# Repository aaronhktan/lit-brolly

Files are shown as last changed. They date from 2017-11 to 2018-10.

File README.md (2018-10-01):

# Lit Brolly

*Nōn omne quod nitet aurum est.*

A project by Aaron Tan, Lily Yang, and [Hengcheng Yu](https://github.com/handchan) to make your brollies lit. The LEDs change colour based on the movement detected by the accelerometer!



---

### Contents
1. [Setup](#setup)
	- [Requirements](#requirements)
	- [Compilation](#compilation)
	- [Hardware](#hardware)
	- [Execution](#execution)
2. [Usage](#usage)
	- [Synergy](#synergy)
	- [Arduino](#arduino)
	- [ADXL345](#adxl345)
3. [Miscellaneous](#miscellaneous)
	- [Acknowledgements](#acknowledgements)
	- [License](#license)

---

## Setup
### Requirements
- Onion Omega2 (should work with the 2+ but this has not been tested)
- Arduino Dock R2
- Neopixels
- ADXL345 accelerometer
- Time. Lots of it.

### Compilation

**Note: Pre-compiled executables are available in the folder ```Code/executable```. Only follow the instructions under the Compilation heading if you really want to compile from source.**

- Set up the virtual machine as described in the PDF labelled "SetupCrossCompilingEnvironmentV1.pdf" in ```Docs/Compile```. In the ```make menuconfig``` step, include the onioni2c library. This will take upwards of an hour of your time.
- Modify the target of the makefile under the compile folder to the name of the file that you wish to compile. By default, it will try to compile ```Synergy.cpp```.
- Move the file you want to compile into the same folder as your ```makefile``` and ```xCompile.sh```.
- Once the makefile, the target, and xCompile.sh are in the same folder, run xCompile.sh as described in the PDF labelled "CompilingCppCodeOmega.pdf" in ```Docs/Compile```. An executable file will be generated in the same folder.

### Hardware
- Solder the Neopixels and hook them up to the Arduino Dock R2 headers as described in the schematic under ```Docs/Schematics```. This project supports hooking up to five strands of Neopixels; connect the power wires in series and data pins to 6, 7, 8, 9, and 10 on the Arduino Dock R2 headers.
- Solder header pins on the ADXL345 as necessary and hook them up to the Onion Expansion headers as described in the schematic under ```Docs/Schematics```.
- A breadboard may prove handy for cable management and organization. See ```Example.png``` under ```Docs/Schematics``` for an real-life example of this schematic put together.

### Execution
- Move your executable to a USB stick, then mount it on your Omega:
	- Connect to your Omega's Wi-Fi network, then using PuTTY on Windows or your terminal on Mac/Linux: ```ssh root@192.168.3.1```. You will need to type in the password for the Omega2: default is onioneer.
	- In the terminal: ```mkdir /mnt/usb``` (first time only, making a directory to be the mount point for your USB stick) then ```mount /dev/sda1 /mnt/usb``` (actually mounting the USB)
- Connect to the Arduino Dock (I prefer wirelessly, but it shouldn't matter), and upload the ```ardu.ino``` sketch under ```Code/src```.
- Run Synergy from the command line: ```/mnt/usb/Synergy``` (assuming you followed the previous directions)
- If you wire up the Neopixels correctly (i.e. the way it's described under the "Final Project Report" appendix), then you should see your Neopixels light up when you move around the accelerometer!

## Usage
### Synergy
Main program; puts everything together (synergy... hahaha get it?). Running the file requires no command line arguments.

- Program will continually pull accelerometer readings every second and output to terminal.
- Lights will change colour every second.
- Generates two log files directly on the Omega2; can be accessed by ```cat```:
	- ```log.txt``` logs, with timestamp, the last readings of the accelerometer and the status of the I2C write command to the Neopixels.
	- ```histogram.txt``` logs, with timestamp of generation time, a histogram of the x, y, and z accelerations as well as total acceleration over the period that the program runs. It is updated every ten seconds with new accelerometer values.
- **Must have ardu.ino sketch running on the Arduino dock for this to work.**

### Arduino
Program to test Neopixels. Starting program requires four integer command line arguments: ```[brightness] [red value] [green value] [blue value]```

- Program sets all Neopixels to the RGB values specified by arguments. Brightness value is vestigial and doesn't actually do anything.
- **Must have ardu.ino running on the Arduino dock for this to work.**

### ADXL345
Program to test the accelerometer. No command line arguments required.

- Pulls accelerometer values every second and outputs to command line.

## Miscellaneous
### Acknowledgements
Big thanks to Austin Jiang for his vehicle.

Big thanks to (Aaaaaaaaaaaaaaaaaaaaaaaa)Kash Pirani for his soldering and head patting skills.

Big thanks to Edward Yang and Shun Yu Rao for moral support and their USB sticks.

Big thanks to Google Assistant, Cortana, and Siri for turning on and off the lights.

Big thanks to Ferrero Rocher for being the Official Snack Food™ of this project.

### License
See LICENSE.md for more details.

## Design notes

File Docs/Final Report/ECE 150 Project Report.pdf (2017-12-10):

# Lit Brolly

Nōn omne quod nitet aurum est.

Aaron Tan
Lily Yang
Hengcheng Yu

Group #25

Project Overview
The idea behind the project was to make a LED Blade Runner inspired umbrella—lining the spokes of a clear umbrella with LEDs and changing their colour and intensity based on the orientation and speed of the umbrella.

To implement this idea, we used the Omega2 to take an input from the accelerometer (through the SDA/SCL pins), mapping these to R, G, and B values from 0-255. We then sent them over to the Arduino over I2C, where the microcontroller sets colour and the intensity and colour of the Neopixel strips through its digital pinouts (6-10).

Originally we intended to communicate with the Neopixel LEDs through SPI; however, the very specific timings required by the Neopixels could not be controlled precisely enough by the Omega2. Instead, we used the I2C and the Arduino Adafruit Neopixel library, which were both better documented, to communicate with the LEDs. We also had stretch goals of allowing users to be able to switch between lighting profiles through a phone or web interface, but this was deemed unfeasible during the timeframe allotted.

Original Features | Final Features
Take input from the accelerometer (through either SPI or I2C) | Take input from the accelerometer through I2C
Take input from a gyroscope (through either SPI or I2C) (not included in our original project proposal but added shortly after submission) | Gyroscope was not used
Change intensity of LEDs (through SPI, backup plan: use Arduino Adafruit Neopixel library) | Control the brightness of the LEDs through the Arduino Adafruit Neopixel library
Change colour of LEDs (through SPI, backup plan: use Arduino Adafruit Neopixel library) | Control the colour of the LEDs through the Arduino Adafruit Neopixel library
Log accelerometer readings | Log accelerometer readings with timestamp, status upon writing I2C values to different registers, and histogram of past accelerometer readings to text files on the Omega
A strand of LEDs along each of the 8 spokes | A strand of LEDs along each of 4 spokes, plus a bonus circular pattern
Allow user to be able to switch lighting profiles through a phone or web interface | Was not implemented, but program can be controlled via SSH to test different colours

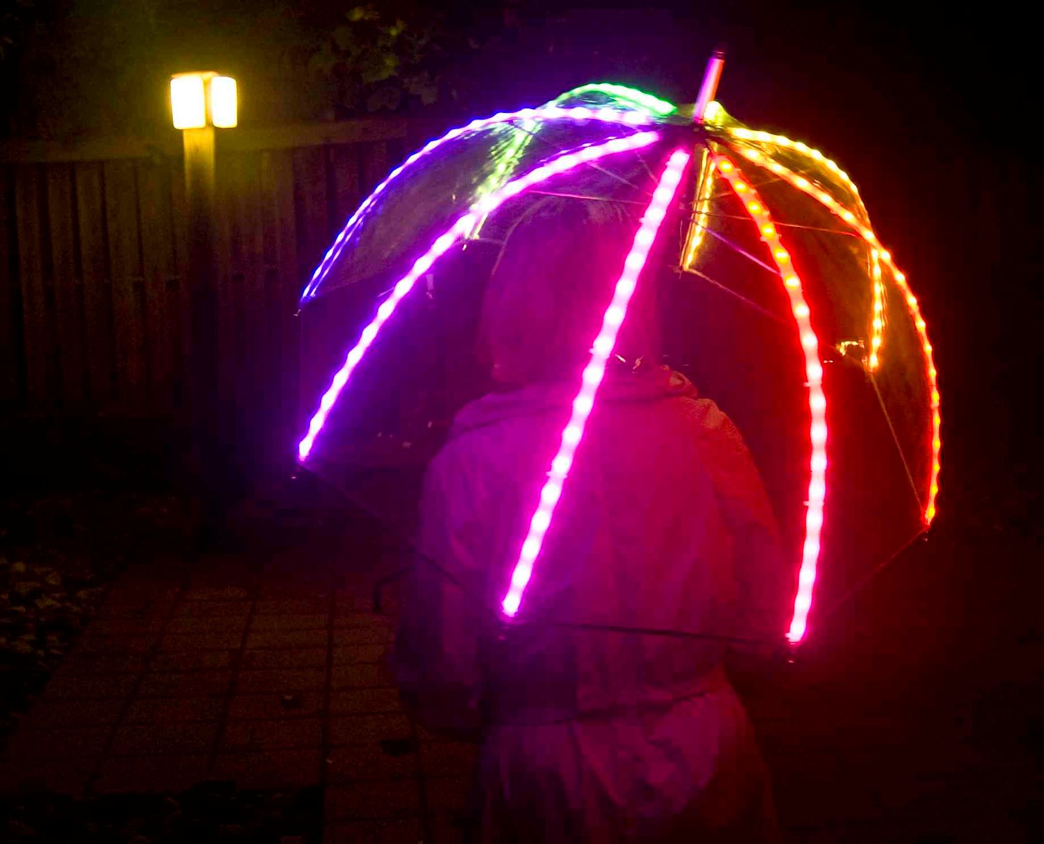
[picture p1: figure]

System Design
Hardware Components:
- Omega2

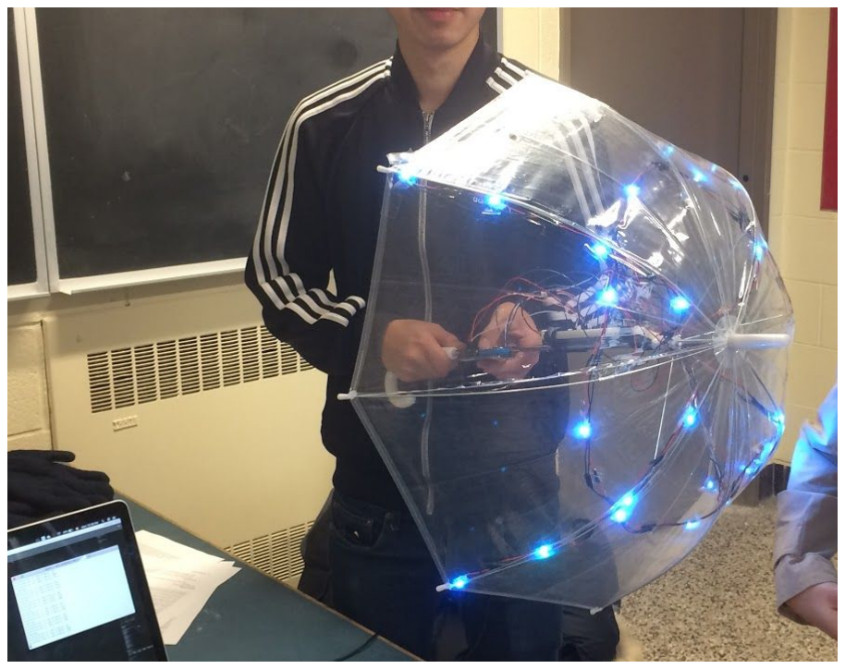
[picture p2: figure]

| ○ We used the Onion Omega2 that was provided for us.
- Arduino Dock R2
| ○ We used the Onion Arduino Dock for the Omega2. The dock has identical pin
layouts to the Arduino and since they share the same microcontroller (the ATMega328P), using the dock with the Onion gives us access to Arduino hardware as a slave device to the Omega2.
- Neopixel LEDs
| ○ We used WS2812B APA102 individually addressable smart full-color LED pixel
made by Kuman.
| ○ We soldered wires to connect them together into a daisy chain. One strip of LEDs
contains 4 individual LEDs and are intended to line one spoke. We hot glued the back of each of the LEDs soldering pads to ensure that the wires would stay in place, then taped the strips to the spokes of the umbrella.
- Accelerometer
| ○ We used a ADXL345 accelerometer module made by OSEPP. It is a 3-axis MEMS
accelerometer with 13-bit resolution measurement at up to +-16 g that can use both SPI and I2C.
| ○ We used I2C to interface with the accelerometer.

- 3.7V 2Ah Lithium-ion Battery and Xiaomi 20Ah Power Bank
- We used a 2Ah battery to power the LEDs through a JST-PH connector connected to the breadboard.
- We used a 20Ah portable power bank to provide power to the Omega through a Micro-USB B connector.
- Wires
- Wires were used to make all the connections.
- Breadboard
- A breadboard was used to house the accelerometer and connect the neopixels and accelerometer to the Arduino Dock.
- The breadboard was strapped onto the handle of the umbrella using tape.
- Resistors
- 5 1k ohm resistors were used for the neopixels (to protect the LEDs).
- 1 10k ohm resistor was used as the pull up resistor to connect the accelerometer to the Arduino Dock (for I2C).
- These resistors were placed on the breadboard.
- Umbrella
- 34 inch child sized clear umbrella.

Software Design
Flowchart for the main program

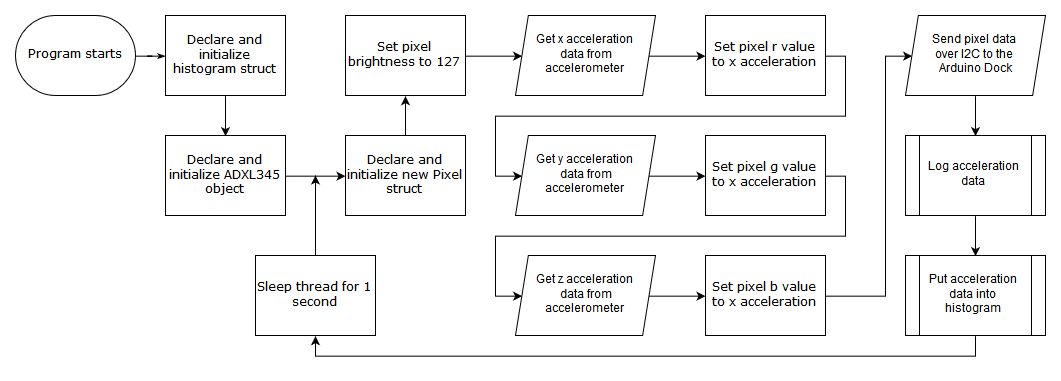
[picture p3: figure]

UML class diagrams for Sensor abstract class and subclasses

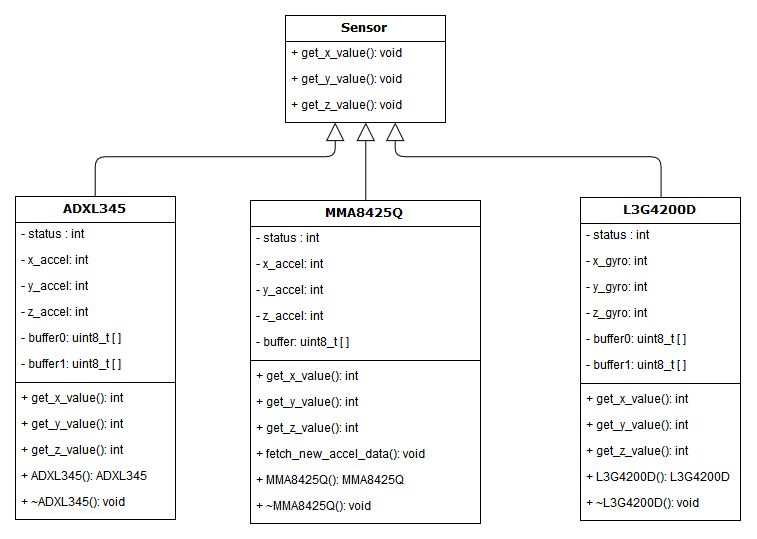
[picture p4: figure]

Class explanations:
- Sensor is an abstract class that has only virtual member functions: get_x_value(), get_y_value(), and get_z_value(). These are meant to be overridden in any child classes, and generically serve to get the x, y, and z, values from any particular sensor.
- ADXL345 is a derived class from base class Sensor. Here, public member functions
get_x_value(), get_y_value(), and get_z_value() have been overridden and
return the x, y, and z accelerations respectively in the form of an int ranging from 0 to 255. We also define a constructor ADXL345() and destructor ~ADXL345() in order to set up the accelerometer correctly (by writing to data registers to tell it to turn on, set sensitivity, and others). In terms of member variables, we have a private status, that changes depending on the success or failure of writing to I2C addresses, x_accel, y_accel, and z_accel, that contain the values of acceleration, and buffer0 and buffer1, which contain the direct readings from the accelerometer (least significant bit and most significant bit respectively).

- MMA8425Q is another derived class from base class Sensor. Here, public member
functions get_x_value(), get_y_value(), and get_z_value() have also been
overridden and return the x, y, and z accelerations respectively in the form of an int ranging from 0 to 255. We define get_new_accel_data() to update the buffer in which acceleration data occurs; here, all the data is contained in one register as opposed to the many in ADXL345 and L3G4200D. We also define a constructor MMA8425Q() and destructor ~MMA8425Q() in order to set up the accelerometer correctly (by writing to data registers to tell it to turn on, set sensitivity, and others). In terms of member variables, we have a private status, that changes depending on the success or failure of writing to I2C addresses, x_accel, y_accel, and z_accel, that contain the values of acceleration, and buffer, which contains 7 bits describing the x, y, and z accelerations detected by the sensor.
- Finally, we have L3G4200D as another derived class from base class Sensor. Here, public
member functions get_x_value(), get_y_value(), and get_z_value() have also
been overridden and return the x, y, and z tilts respectively in the form of an int ranging from 0 to 255. Unlike the other two subclasses, the L3G4200D returns tilts rather than acceleration from the same function name; a great example of runtime polymorphism in C++! We also define a constructor L3G4200D() and destructor ~L3G4200D() in order to set up the gyroscope correctly (by writing to data registers to tell it to turn on, activate three axes, and more). In terms of member variables, we have a private status, that changes depending on the success or failure of writing to I2C addresses, x_gyro, y_gyro, and z_gyro, that contain the values of tilt in each axis, and and buffer0 and buffer1, which contain the direct readings from the gyroscope (least significant bit and most significant bit respectively).

Struct explanations:

typedef struct Pixel {
int brightness;
int r;
int g;
int b;
} Pixel;

The Pixel struct is a structured data type that groups together information about a pixel: how bright it should be, as well as its red, green, and blue intensities.

typedef struct Histogram { int accel[5];
int histx[5];
int histy[5];
int histz[5];
} Histogram;

The Histogram struct is a structured data type that declares integer arrays of 5 buckets that acceleration data can be grouped into.

System dependent/independent components:
When writing software for this project, because our project was very close to the metal and interfaced very directly with the hardware that we used, there were many system dependent components:
- Each accelerometer/gyroscope class is system dependent because the slave addresses are unique for each piece of hardware (e.g. 0x1C, 0x53, and 0x68 for ADXL345, MMA8425Q, and L3G4200D respectively). In addition, each sensor has different data registers to read/write from in order to extract useful data.
- The Sketch running on the Arduino dock can be used by any Arduino, but it must be an Arduino-compatible board (such as the Arduino Dock we have!). Therefore, it is system dependent.
- The code to control the Neopixels uses a library specifically written to control these types of LEDs, thus that software component is also system dependent.

Nonetheless, our project also had several system independent components in software:
- The logging infrastructure was completely software independent and could be tested by feeding dummy values into the function. It does not depend on a specific piece of hardware to work (theoretically, all it needs is three values that change over time); thus, it is system independent.
- The abstract class Sensor is system independent, as all of its functions are purely virtual. Because of that, it cannot be instantiated and all its member functions must be overridden in any subclasses. Thus, it could be used for any Sensor that returns x, y, and z values and is system independent.

Logging infrastructure:
During every loop of the main function, logging is performed, with timestamps.
- The status of the I2C write action is logged (where 0 is success and !0 is failure) in a log.txt file.
- The accelerometer values are logged in the log.txt file.
- Acceleration data is added to a histogram and then written every ten seconds to a histogram.txt file. Data manipulation is performed on the acceleration x, y, and z-values to calculate a total acceleration; this is also logged in histogram.txt.
- These files can be viewed from the command line with cat log.txt or cat
histogram.txt

Source code files:
- Synergy.cpp
- This is the main program, with all the class definitions and logic.
- Makefile
- This is the file that tells the compiler how to compile the program
- xCompile.sh
- This is the shell script that we use to compile the program.
- Ardu.ino

- This is the sketch that runs on the Arduino Dock to receive commands over the SDA/SCL pins from the Omega2.

Testing
Testing all the components took the most time during this project. We tested our components first using Arduino and then with the Omega2, because using an Onion was very time-consuming and it would be hard to tell whether a problem was hardware or software related. The pins on the Arduino Dock and the Arduino are also identical which makes the connections very similar for both the boards when we would eventually transfer the hardware over.

First, we used an Arduino and breadboard to test each individual LED. Once we verified that each LED was functional we soldered them together into a strand and tested the strand. This was necessary since if one LED in the strand was not functioning then the strand would not light up.

We also used the Arduino to test to accelerometer (both of them) and the gyroscope. The gyroscope was originally working but then after and soldering accident, it ceased to function. This was evident when we tested it with the Arduino code. The accelerometer never gave out an output when we tried to test it leading us to purchase another accelerometer. When we verified that the new accelerometer was in working condition (using the Arduino), we tested it with the Omega2.

We wrote a small command line program to output accelerometer readings every second to the command line in order to test the new accelerometer. We tilted, left it in place, and played around with it to make sure that our readings were consistent with the motion that the accelerometer was experiencing.

After we wired up the Neopixels and the accelerometer, we mashed the code together and tested the lights to make sure that they were lighting up in ways that we expected. When large amounts of movement happened, lights glowed in beautiful, strange ways; when left alone, it usually reverted to a bright white colour. These results were consistent with what we expected to see.

Limitations
Our project has some limitations as an umbrella, as the components of our project affect some primary functions of the umbrella. The wiring made it very difficult to close and open the umbrella, due to stretching and the breadboard being glued to the center handle. The Omega2, Arduino Dock and battery were very bulky and reduced the portability of the umbrella.

In addition, we initially believed that we could run our NeoPixel LEDs directly off the Omega2 with C or C++ code. However, after testing extensively for over 30 hours we could not get the NeoPixel libraries to work with the Omega2. This testing included using the provided libonionneopixel, the neopixel_Cwrapper, looking up the source code for the implementation of the functions defined in these header files, and trying some code ourselves. In the end, we decided to use the Omega2 to communicate with Arduino sketches to control the NeoPixels.

Lessons Learned
We learnt many lessons throughout this project.

First, hardware is very fragile. At first we bought both an accelerometer and a gyroscope but we weren’t able to use either of these original components in our project. While soldering the header pins onto the gyroscope, an accident rendered the gyroscope unuseable. No matter how many times we tested the accelerometer, we could not get an output, leading us to conclude either we broke it somehow accidentally or it was dead on arrival. We ended up buying another accelerometer which we used for the project.

If we were to start the project again, we would buy a different accelerometer and gyroscope. The original ones we bought were hard to work with and might have been defective upon arrival. We also would probably have started with I2C instead of SPI to test the accelerometer and the gyroscope, because I2C lead to better results with the second accelerometer.

Secondly, we learned that soldering can be a difficult beast to tame. During the project, soldering took up a significant portion of the time, and required full concentration. To improve on our process, we would also have used a better soldering iron (such as one with variable temperature and a new tip) to avoid accidents and make the process faster and smoother. We would have also soldered in an environment with better ventilation to avoid long term health damage.

Lastly, we would have also done more research on the Neopixels and its compatibility with the Omega2. We spent a lot of time trying to control the Neopixels directly (without Arduino code) from the Omega2, a task we now think is borderline impossible. If we started over today, we would skip directly to controlling the Neopixels through the Arduino Dock instead of trying to work them directly through the Power Dock.

Overall, this project was a lot of fun and gave us a pretty cool introduction to embedded computing!

Appendix

Peer Contribution:
- Aaron Tan:
- Software: Classes, I2C, main program logic, style editing
- Hardware: Wire stripping and hardware QA with Omega2 and Arduino Dock
- Miscellaneous: Set up the virtual machine on three different laptops from source
- Lily Yang:
- Software: Logging infrastructure
- Hardware: Setting up the circuit on breadboard with accelerometer and complete strands, soldering
- Miscellaneous: Bought most of the materials, making multiple hour-long trips to distant lands
- Hengcheng Yu:
- Software: Arduino sketch, debugging, code review
- Hardware: Lots of soldering, setting up the strands
- Miscellaneous: Wired up umbrella and attached bread board to handle, supplied bubble tea

We also give a special thanks to Austin Jiang for driving us to places so we could buy emergency accelerometers!

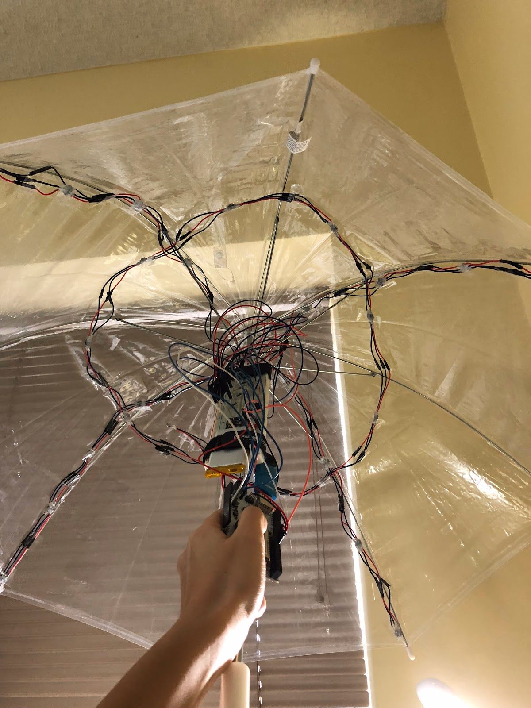
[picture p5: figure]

Figure 1: The finished umbrella.

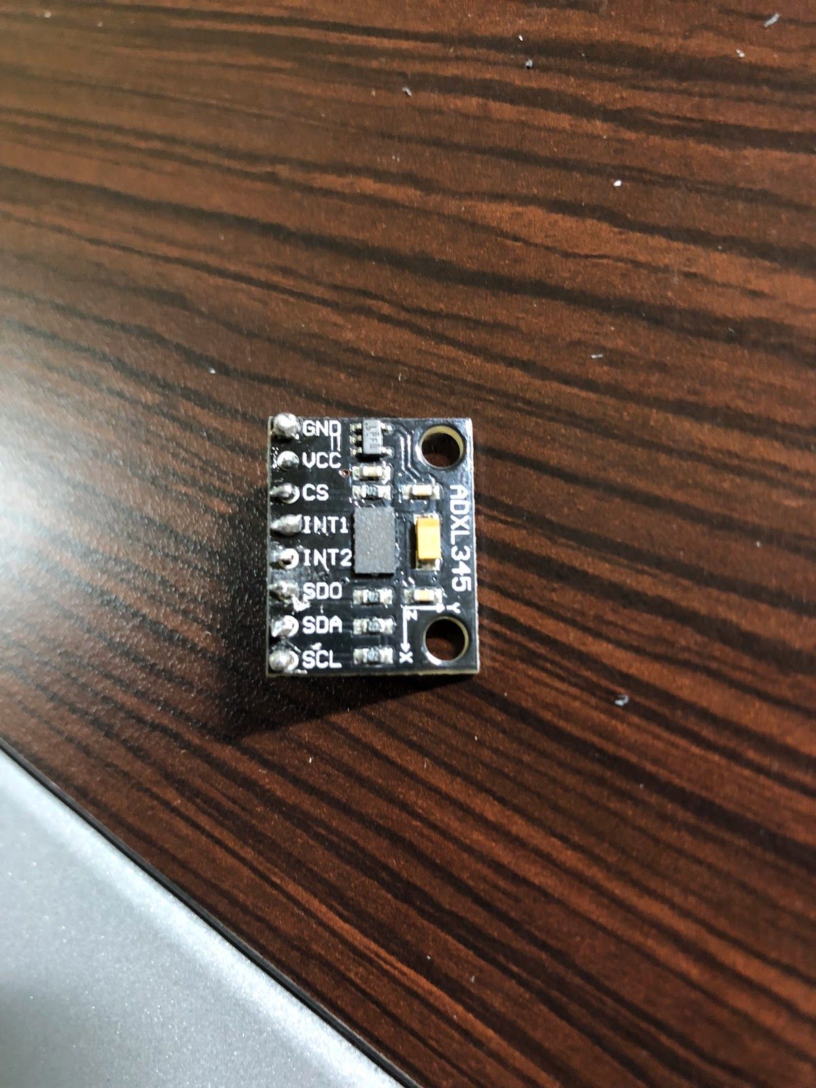
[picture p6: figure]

Figure 2: The accelerometer that was used in this project(ADXL345).

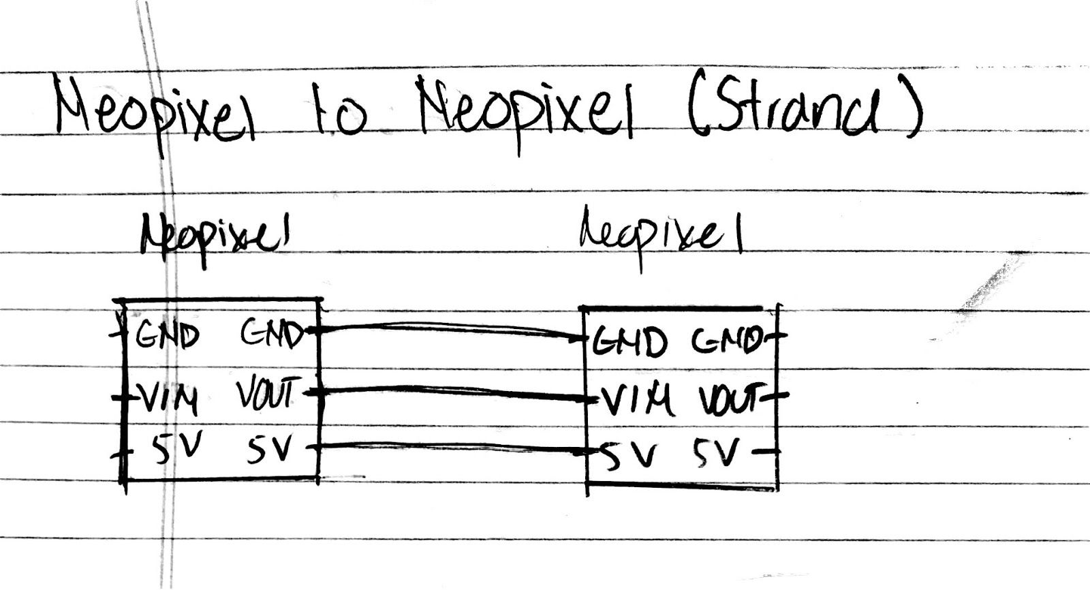
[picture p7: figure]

Figure 3: Neopixel to Neopixel connection.

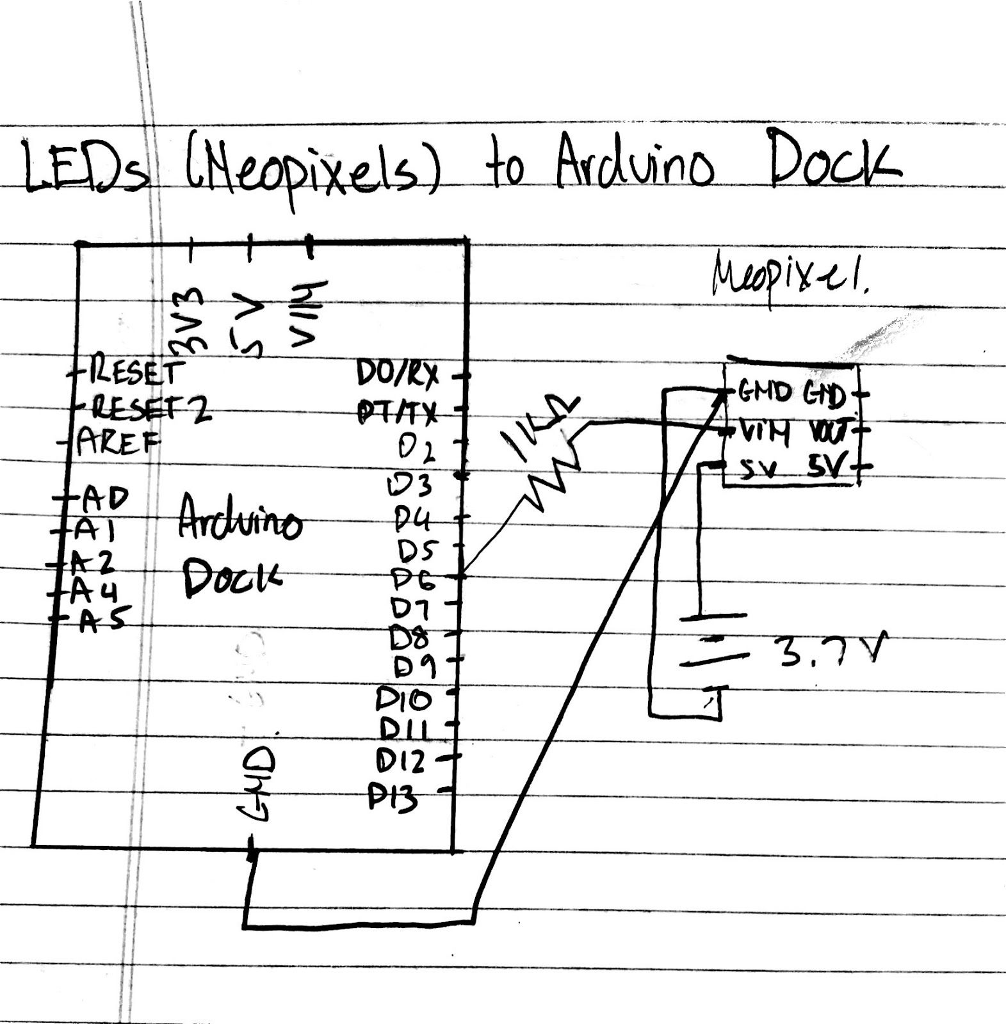
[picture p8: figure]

Figure 4: Neopixel to Onion (using Arduino Dock) connection.

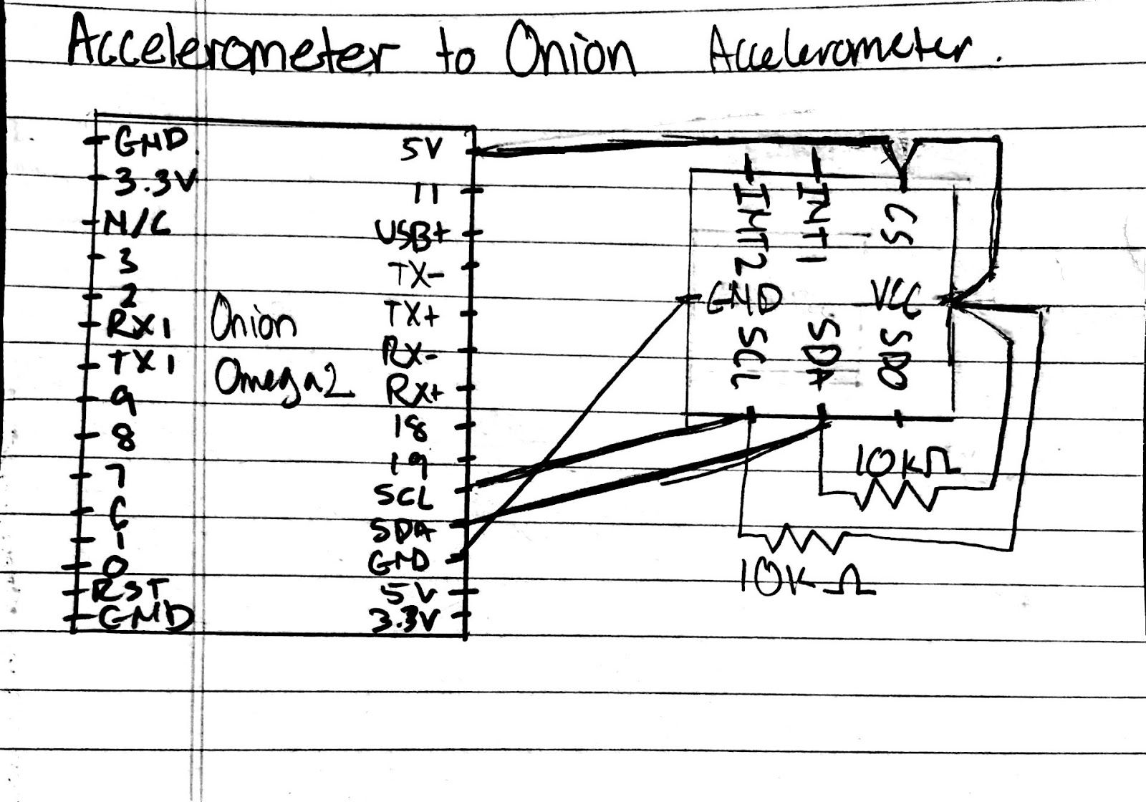
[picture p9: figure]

Figure 5: Accelerometer to Onion (using Arduino Dock) connection.

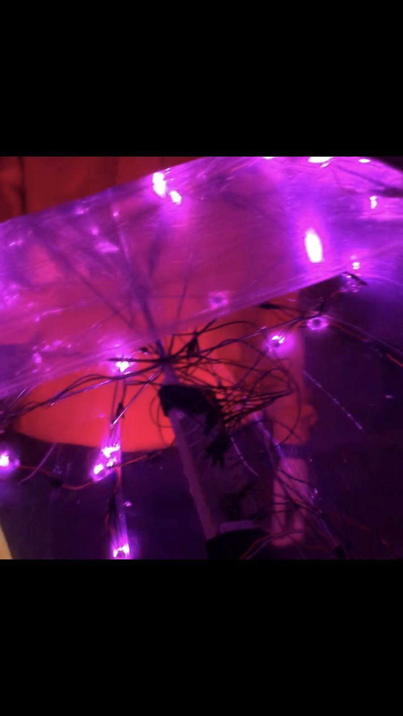
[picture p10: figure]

Figure 6: The umbrella in the dark.

Source code:

Synergy.cpp:

#include <onion-i2c.h>

#include <iostream>

#include <fstream>

#include <ctime>

#include <cmath>

#define NEOPIXEL_I2C_DEVICE_NUM 0 #define DEV_ADDRESS 0x08

// Abstract Sensor class
class Sensor {
public:
// Pure virtual functions to get x, y, and z accelerations virtual int get_x_value() = 0;
virtual int get_y_value() = 0;
virtual int get_z_value() = 0;
};

/****************************** ADXL345 ******************************/
/* The ADXL345 is a small ultralow power 3-axis accelerometer. * There are many others like it, but this one is mine.
*/

// Derived class ADXL345 is a subclass of the Sensor
class ADXL345 : public Sensor {
public:
// Concrete implementation of virtual functions int get_x_value();
int get_y_value();
int get_z_value();

// Constructor and destructors ADXL345();
~ADXL345();
private:
int status, x_accel, y_accel, z_accel;
uint8_t *buffer0, *buffer1; // buffer0 contains least significant bit, buffer1 contains most significant bit

};

// Setup the ADXL345
ADXL345::ADXL345() {
// Initialize some variables status = 0;
buffer0 = new uint8_t[2];
buffer1 = new uint8_t[2];

// i2c_write(devNum, devAddr, addr, val)
// The ADXL345 has an address of 0x53 (83); writing 0x0A (10) to 0x2C (44, bandwidth rate register) sets the output data rate to 100Hz. status = i2c_write(0, 0x53, 0x2C, 0x0A);

// Writing 0x08 (08) to 0x2D (45, power control register) disables auto-sleep.
status = i2c_write(0, 0x53, 0x2D, 0x08);

// Writing 0x08 (08) to 0x31 (49) sets the sensitivity to +/-2g, with self-test disabled and 4-wire interface.
status = i2c_write(0, 0x53, 0x31, 0x08);

std::cout << "Status after setup is " << status << std::endl; }

// Clean up after ourselves!
ADXL345::~ADXL345() {
delete[] buffer0;
delete[] buffer1;
}

// Get x-values
int ADXL345::get_x_value() {
status = i2c_read(0, 0x53, 0x32, buffer0, 1); // i2c_read(devNum, devAddr, addr, buffer, numbytes)
status = i2c_read(0, 0x53, 0x33, buffer1, 1); // 0x32 to 0x37 contain acceleration data

// Now that we have the data, convert it to 10-bits with some magic numbers
int x_accel = (buffer1[0] & 0x03 * 256) + buffer0[0];
if (x_accel > 511) {
x_accel -= 1024;

}

return x_accel;
}

// Get y-values
int ADXL345::get_y_value() {
status = i2c_read(0, 0x53, 0x34, buffer0, 1);
status = i2c_read(0, 0x53, 0x35, buffer1, 1);

int y_accel = (buffer1[0] & 0x03 * 256) + buffer0[0]; if (y_accel > 511) {
y_accel -= 1024;
}

return y_accel;
}

// Get z-values
int ADXL345::get_z_value() {
status = i2c_read(0, 0x53, 0x36, buffer0, 1);
status = i2c_read(0, 0x53, 0x37, buffer1, 1);

int z_accel = (buffer1[0] & 0x03 * 256) + buffer0[0]; if (z_accel > 511) {
z_accel -= 1024;
}

return z_accel;
}

/****************************** MMA8452Q ******************************/
/* The MMA8425Q is another 3-axis accelerometer.
* Ours broke. Also, SPI doesn't seem to work on this thing. Very sad. :(
*/

// Derived class MMA8425Q is a subclass of the Sensor class MMA8452Q : public Sensor {
public:
// Concrete implementation of virtual functions

int get_x_value();
int get_y_value();
int get_z_value();

// Put accelerometer data into the buffer void fetch_new_accel_data();

// Constructor and destructors MMA8452Q();
~MMA8452Q();
private:
int status, x_accel, y_accel, z_accel;
uint8_t *buffer; // buffer contains all accelerometer data };

// You get an MMA8452Q! You get an MMA8452Q! Everybody gets an MMA8452Q!
MMA8452Q::MMA8452Q() {
// Initialize some variables
status = 0;
buffer = new uint8_t[7];

// i2c_write(devNum, devAddr, addr, val, numBytes)
// The MMA8452Q has an address of 0x1C (28); writing 0x01 to 0x2A activates the accelerometer.
status = i2c_write(0, 0x1C, 0x2A, 0x01);

// Writing 0x00 to 0x0E sets the sensitivity to +/-2g. This could be changed to 01 or 10 for 4 and 8 respectively.
status = i2c_write(0, 0x1C, 0x0E, 0x00);

std::cout << "Status after setup is " << status << std::endl;
}

// Clean up, clean up, everybody clean up
MMA8452Q::~MMA8452Q() {
delete[] buffer;
}

// Read accelerometer values over I2C and put them into the buffer void MMA8452Q::fetch_new_accel_data() {
status = i2c_read(0, 0x1C, 0x00, buffer, 7); // i2c_read(devNum, devAddr, addr, buffer, numbytes)

}

// Get x-values
int MMA8452Q::get_x_value() {
// Now that we have the data, convert it (see datasheet AN4076 for data manipulation details)
int x_accel = (buffer[1] * 256 + buffer[2]) / 16;
if (x_accel > 2047) {
x_accel -= 4096;
}

return x_accel;
}

// Get y-values
int MMA8452Q::get_y_value() {
int y_accel = (buffer[3] * 256 + buffer[4]) / 16; if (y_accel > 2047) {
y_accel -= 4096;
}

return y_accel;
}

// Get z-values
int MMA8452Q::get_z_value() {
int z_accel = (buffer[5] * 256 + buffer[6]) / 16; if (z_accel > 2047) {
z_accel -= 4096;
}

return z_accel;
}

/****************************** L3G4200D ******************************/
/* The L3G4200D is a 3-axis gyroscope / angular rate sensor.
* Ours got into a sad soldering accident and perished bravely on the front lines.
*/

// Derived class L3G4200D is a subclass of the Sensor
class L3G4200D : public Sensor {

public:
// Concrete implementation of virtual functions int get_x_value();
int get_y_value();
int get_z_value();

// Constructor and destructors L3G4200D();
~L3G4200D();
private:
int status, x_accel, y_accel, z_accel;
uint8_t *buffer0, *buffer1; // buffer0 contains LSB, buffer1 contains MSB
};

// Set up the gyroscope
L3G4200D::L3G4200D() {
// Initialize all the variables status = 0;
buffer0 = new uint8_t[2];
buffer1 = new uint8_t[2];

// i2c_write(devNum, devAddr, addr, val, numBytes)
// The L3G4200D has an address of 0x68 (104); writing 0x0F (15) to 0x20 (32) activates X, Y, and Z axis.
status = i2c_write(0, 0x68, 0x20, 0x0F);

// Writing 0x30 (48) to 0x23 (35) sets mode to continuous update, data lsbat lower address, fsr 2000dps, self-test enabled, and 4-wire interface
status = i2c_write(0, 0x168, 0x23, 0x30);
}

// Clean up after ourselves L3G4200D::~L3G4200D() {
delete[] buffer0;
delete[] buffer1;
}

// 0x28 (40) and 0x29 (41) contain all the x-axis data from the gyro, LSB first.
int L3G4200D::get_x_value() {

status = i2c_read(0, 0x68, 0x28, buffer0, 2); // i2c_read(devNum, devAddr, addr, buffer, numbytes)
status = i2c_read(0, 0x68, 0x29, buffer1, 2);

// Now that we have the data, convert it
int x_gyro = (buffer1[0] * 256 + buffer0[0]); if (x_gyro > 32767) {
x_gyro -= 65536;
}

return x_gyro;
}

// Now do for y-values from 0x2A and 0x2B
int L3G4200D::get_y_value() {
status = i2c_read(0, 0x68, 0x2A, buffer0, 2); status = i2c_read(0, 0x68, 0x2B, buffer1, 2);

int y_gyro = (buffer0[2] * 256 + buffer1[0]); if (y_gyro > 32767) {
y_gyro -= 65536;
}

return y_gyro;
}

// Now do for z-values from 0x2C and 0x2D
int L3G4200D::get_z_value() {
status = i2c_read(0, 0x68, 0x2C, buffer0, 2); status = i2c_read(0, 0x68, 0x2D, buffer1, 2);

int z_gyro = (buffer0[1] * 256 + buffer1[0]); if (z_gyro > 32767) {
z_gyro -= 65536;
}

return z_gyro;
}

/****************************** Pixel ******************************/ /* Struct declaration to hold data about how to light the Neopixels Typedef for convenience when initializing */

typedef struct Pixel {
int brightness;
int r;
int g;
int b;
} Pixel;

/****************************** Logging ******************************/
// We are the lumberjacks

// Histogram container struct
typedef struct Histogram { int accel[5];
int histx[5];
int histy[5];
int histz[5];
} Histogram;

// Function to log data in a file
void file_log(Pixel pixel, int status) {
std::ofstream file; // Make the text file to log everything in file.open("log.txt"); // Open the file

if (file.is_open()) {
std::time_t time = std::time(NULL); // Current time and date using ctime

char* dt = std::ctime(&time); // Convert to string form

// Put it in the text file
if (pixel.r > 255 || pixel.g > 255 || pixel.b > 255 || pixel.r < 0 || pixel.g < 0 || pixel.b < 0) {
file << dt << '\t' << "[ERROR]: The accelerometer values are incorrect" << std::endl;
} else {
file << dt << '\t' << "[DEBUG]: Accelerometer values are acceptable" << std::endl;

}

if (status != 0) {

file << dt << '\t' << "[ERROR]: Something went wrong while sending data over I2C" << std::endl; } else {
file << dt << '\t' << "[DEBUG]: No errors while sending data over I2C" << std::endl;
}

file << dt << '\t' << "[INFO]: Intensity of the pixels: " << pixel.brightness << std::endl;
file << dt << '\t' << "[INFO]: Acceleration in the X-Axis: " << pixel.r << std::endl;
file << dt << '\t' << "[INFO]: Acceleration in the Y-Axis: " << pixel.g << std::endl;
file << dt << '\t' << "[INFO]: Acceleration in the Z-Axis: " << pixel.b << std::endl;
}

file.close();
}

// Function to initialize histogram
void initialize_histogram(Histogram &histogram) {
for(int x = 0; x < 5; x++) { // Initialize values to 0 histogram.accel[x] = 0;
histogram.histx[x] = 0;
histogram.histy[x] = 0;
histogram.histz[x] = 0;
}
}

// Function to put values into their buckets
void input_histogram(Histogram &histogram, Pixel pixel) {
double accel = sqrt(pow(pixel.r , 2) + pow(pixel.b , 2) + pow(pixel.g , 2)); // Calculate total acceleration

if (accel >= 0 && accel < 50) { // Drop some accelerations into those bins
histogram.accel[0]++;
} else if (accel >= 50 && accel < 100) {
histogram. accel[1]++;
} else if (accel >= 100 && accel < 150) { histogram.accel[2]++;
} else if (accel >= 150 && accel < 200) {

histogram.accel[3]++;
} else if (accel <= 200) {
histogram.accel[4]++;
}

if (pixel.r >= 0 && pixel.r < 50) { // Drop some Reds into those bins
histogram.histx[0]++;
} else if (pixel.r >= 50 && pixel.r < 100) { histogram.histx[1]++;
} else if (pixel.r >= 100 && pixel.r < 150) { histogram.histx[2]++;
} else if (pixel.r >= 150 && pixel.r < 200) { histogram.histx[3]++;
} else if (pixel.r >= 200 && pixel.r <= 255) { histogram.histx[4]++;
}

if (pixel.b >= 0 && pixel.b < 50) { // Drop some Blues into those bins
histogram.histy[0]++;
} else if (pixel.b >= 50 && pixel.b < 100) { histogram.histy[1]++;
} else if (pixel.b >= 100 && pixel.b < 150) { histogram.histy[2]++;
} else if (pixel.b >= 150 && pixel.b < 200) { histogram.histy[3]++;
} else if (pixel.b >= 200 && pixel.b <= 255) { histogram.histy[4]++;
}

if (pixel.g >= 0 && pixel.g < 50) { // Drop some Greens into those bins
histogram.histz[0]++;
} else if (pixel.g >= 50 && pixel.g < 100) { histogram.histz[1]++;
} else if (pixel.g >= 100 && pixel.g < 150) { histogram.histz[2]++;
} else if (pixel.g >= 150 && pixel.g < 200) { histogram.histz[3]++;
} else if (pixel.g >= 200 && pixel.g <= 255) { histogram.histz[4]++;
}

}

// Function to write histogram to a file void write_histogram(Histogram histogram) { std::ofstream file;
file.open("histogram.txt");

if(file.is_open()){
std::time_t time = std::time(NULL); // Current time and date using ctime
char* dt = std::ctime(&time); // Convert to string form
file << "Generated " << dt << std::endl;

file << "Value" << '\t' << "X-acc: " << '\t' << "Y-acc" << '\t' << "Z-acc" << '\t' << "Total Acceleration" << std::endl;
file << "0-49" << '\t' << histogram.histx[0] << '\t' << histogram.histy[0] << '\t' << histogram.histz[0] << '\t' << histogram.accel[0] << std::endl;
file << "50-99" << '\t' << histogram.histx[1] << '\t' << histogram.histy[1] << '\t' << histogram.histz[1] << '\t' << histogram.accel[1] << std::endl;
file << "100-149" << '\t' << histogram.histx[2] << '\t' << histogram.histy[2] << '\t' << histogram.histz[2] << '\t' << histogram.accel[2] << std::endl;
file << "150-199" << '\t' << histogram.histx[3] << '\t' << histogram.histy[3] << '\t' << histogram.histz[3] << '\t' << histogram.accel[3] << std::endl;
file << "200-255" << '\t' << histogram.histx[4] << '\t' << histogram.histy[4] << '\t' << histogram.histz[4] << '\t' << histogram.accel[4] << std::endl;
}

file.close();
}

/****************************** Main Logic ******************************/
int main(const int argc, const char* const argv[]) {

Histogram histogram; // Set up the histogram initialize_histogram(histogram);

int status = 0; // Keeps track of whether things worked

ADXL345 accelerometer; // Instantiate ADXL345 object (and set up the accelerometer)

// Our MMA8425Q broke so we are no longer using this code
// MMA8452Q accelerometer; // Instantiate MMA8425Q object (and set up the accelerometer)

// Our L3G4200D got into an accident involving solder so we are no longer using this code
// L3G4200D gyro; // Instantiate L3G4200D object (and set up the gyroscrope)

sleep(1); // Sleep for a second to make sure that changes have propagated

// Infinite loop to continuously grab data from the accelerometer and then push the changes to the LEDs
for (int i = 0; i > -1; i += 0) {
std::cout << "Looping..." << std::endl;

// Initialize a pixel with default brightness values and RGB values based on the X, Y, and Z readings from accelerometer
Pixel pixel;
// pixel.brightness = gyro.get_x_value; // The gyro can no longer be used.
pixel.brightness = 127;
pixel.r = accelerometer.get_x_value();
pixel.g = accelerometer.get_y_value();
pixel.b = accelerometer.get_z_value();

// FOR TESTING PURPOSES DO NOT UNCOMMENT UNLESS YOU KNOW WHAT YOU'RE DOING
// i2c_writeBytes(NEOPIXEL_I2C_DEVICE_NUM, DEV_ADDRESS, pixel.brightness, 0x01, 0);
// i2c_writeBytes(NEOPIXEL_I2C_DEVICE_NUM, DEV_ADDRESS, 255, 0x01, 0);
// i2c_writeBytes(NEOPIXEL_I2C_DEVICE_NUM, DEV_ADDRESS, 0, 0x01, 0);
// i2c_writeBytes(NEOPIXEL_I2C_DEVICE_NUM, DEV_ADDRESS, 0, 0x01, 0);

/* Use I2C to communicate with the Arduino dock: change values with #defines at top of file
int i2c_writeBytes (int devNum, int devAddr, int addr, int val, int numBytes)
devNum is always 0 for Arduino dock
devAddr for the ATMega is 0x08 by default unless you change it on the Omega itself
addr to write to is the value that we want to transmit to the microcontroller, to be read with Wire library
val to be written is a dummy value because we specify that we write 0 bytes of data */
status = i2c_writeBytes(NEOPIXEL_I2C_DEVICE_NUM, DEV_ADDRESS, pixel.brightness, 0x01, 0);
status = i2c_writeBytes(NEOPIXEL_I2C_DEVICE_NUM, DEV_ADDRESS, pixel.r, 0x01, 0);
status = i2c_writeBytes(NEOPIXEL_I2C_DEVICE_NUM, DEV_ADDRESS, pixel.g, 0x01, 0);
status = i2c_writeBytes(NEOPIXEL_I2C_DEVICE_NUM, DEV_ADDRESS, pixel.b, 0x01, 0);

// Print out the data for verification in terminal std::cout << "Acceleration in the X-Axis: " << pixel.r << std::endl;
std::cout << "Acceleration in the Y-Axis: " << pixel.g << std::endl;
std::cout << "Acceleration in the Z-Axis: " << pixel.b << std::endl;

// Log ALL THE THINGS
file_log(pixel, status);
input_histogram(histogram, pixel); // Put new values into histogram
if (!(i % 10)) { // Runs only once every ten seconds to minimize load on Omega
write_histogram(histogram);
}

// Sleep for a second to make it look nicer sleep(1);
}

return 0;
}

Ardu.ino:

#include <Adafruit_NeoPixel.h> #include <Wire.h>

#ifdef __AVR__

#include <avr/power.h>

#endif

// Data pins for the eight Neopixel strands #define PIN_NEO_0 6
#define PIN_NEO_1 7

#define PIN_NEO_2 8

#define PIN_NEO_3 9

#define PIN_NEO_4 10

#define NUMBER_OF_STRANDS 5

// Struct declaration, where member variables change how a pixel is lit
typedef struct Pixel {
int r;
int g;
int b;
int brightness;
} Pixel;

// Initialize an array of strands with each strand's data pin set Adafruit_NeoPixel strip[NUMBER_OF_STRANDS] = { Adafruit_NeoPixel(60, PIN_NEO_0, NEO_GRB + NEO_KHZ800), Adafruit_NeoPixel(60, PIN_NEO_1, NEO_GRB + NEO_KHZ800), Adafruit_NeoPixel(60, PIN_NEO_2, NEO_GRB + NEO_KHZ800), Adafruit_NeoPixel(60, PIN_NEO_3, NEO_GRB + NEO_KHZ800), Adafruit_NeoPixel(60, PIN_NEO_4, NEO_GRB + NEO_KHZ800), };

int transmission_number = 0;
Pixel pixel, previous_pixel;

void setup() {
pinMode(LED_BUILTIN, OUTPUT); // Turn off that blue LED on the Arduino dock (because it is ugly)
digitalWrite(LED_BUILTIN, LOW);

Wire.begin(0x08); // Listen for input on 0x08, the device address of the Arduino dock
Wire.onReceive(i2c_on_receive_handler);

// Loop through all the strands to set them up
for (int i = 0; i < NUMBER_OF_STRANDS; i++) { strip[i].begin(); // Prepares data pin for Neopixel output strip[i].show(); // Turns off all Neopixels at the beginning }
}

void loop() {
// Nothing to see here friendos! :)
}

// Fires when data is passed from the Omega to the Arduino dock void i2c_on_receive_handler(int bytes_num) {

/* Depending on which transmission over I2C this is, we set different member variables of the Pixel
* First, brightness, then R, G, B, and finally, we show the pixels. */

switch(transmission_number) {
case 0:
pixel.brightness = Wire.read(); transmission_number++;
break;
case 1:
pixel.r = Wire.read();
transmission_number++;
break;
case 2:
pixel.g = Wire.read();
transmission_number++;
break;
case 3:
pixel.b = Wire.read();
for (int i = 0; i < NUMBER_OF_STRANDS; i++) { // Loop through every strand and every pixel to set colour
for (uint16_t j = 0; j < strip[i].numPixels(); j++) { strip[i].setPixelColor(j, pixel.r, pixel.g, pixel.b);

strip[i].show();
}
}
transmission_number = 0;
break;
}
}

Makefile (slightly modified from sample in class):

# main compiler

#CC := g++

TARGET1 := Synergy

all: $(TARGET1)

$(TARGET1):
@echo "Compiling C++ program"
$(CXX) $(CFLAGS) $(TARGET1).cpp -o $(TARGET1) $(LDFLAGS) $(LIB)

clean:
@rm -rf $(TARGET1) $(TARGET2)

Bibliography

Burgess, P. (2017, October 13). Adafruit Neopixel Uberguide. Retrieved December 1, 2017, from https://cdn-learn.adafruit.com/downloads/pdf/adafruit-neopixel-uberguide.pdf

Onion Omega2 Documentation. (2017, November 13). Retrieved December 04, 2017, from https://docs.onion.io/omega2-docs/

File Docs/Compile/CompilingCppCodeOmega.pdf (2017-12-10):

# Compiling C++ Code for the Omega

What you will need:

1. Linux Environment – most likely the vdi file given to you
2. Optional (Windows Users) - PuTTy – get from putty.org

## 1 Compiling the program – Using Only Standard Libraries

What you will Need:

1. A sample .cpp file, such as HelloWorld.cpp

The goal now is to compile this .cpp for the mips architecture so it can run on
the omega, this is done by running the cross compiler for c++ code with your
.cpp file, which can be found here:
- ~/source/staging dir/toolchain-mipsel 24kc gcc-5.4.0 musl/bin/mipsel-openwrtlinux-g++

The Full command to compile your .cpp file is the following:

$ ~/source/staging dir/toolchain-mipsel 24kc gcc-5.4.0 musl/bin/mipsel-openwrtlinux-g++ <file> -o <output file>

At this point there should be an executable file in the directory that your .cpp
file is in.

## 2 Compiling the program – Using Non-Standard Libraries

What you will Need:

1. A sample .cpp file using external libraries, such as gpioread.cpp which can be found in the folder c-cross-compile-example as gpioread.c, simply rename the file to gpioread.cpp

To compile to mips architecture with cpp code we will need to make a couple changes to the makefile in the c-cross-compile-example folder.

1

November 19, 2017 | ECE 150
- open the makefile for editing
- change the line that says: CC := gcc to CXX := g++
- change the line starting with TARGET1 := gpioread to TARGET1 := <filename>, where the <filename> is replaced with the name of your .cpp file
- change the line starting with $(CC) to start with $(CXX)
- change the extension on the same line after $(TARGET1) to .cpp

Now to compile your program run the following command (assuming the xCompile.sh script is in your directory with the makefile and .cpp file):

$ sh xCompile.sh -buildroot /root/source/ -lib <put Libraries Here>

At this point there should be an executable file with the same name as your .cpp in the directory that your .cpp file is in.

## 3 Getting the file to your omega – Using a USB-Stick

What you will need:

1. A .exe file that has been cross compiled
2. a USB stick formatted to either exFat or Fat32
- Turn on drag and drop for your virtual machine. to do this go to the settings in virtual box, and in the general menu go to the advanced sub-menu and change the drag’n’drop item to ’bidirectional’. this will allow you to drag and drop files between your regular OS and the virtual machine, you may need to restart the virtual machine for this to take effect.
- drag the executable from the virtual machine onto the desktop of your regular OS
- put this file onto your USB-Stick
- put the USB-Stick into the Omega 2 dock
- SSH to the omega, look at section 5 if unaware of how to do this

$ cd /tmp/mounts/USB-A1

∗ If this does not work go to section 6 for troubleshooting then continue
$ ./<executable file>

2

November 19, 2017 | ECE 150

## 4 Getting the file to your Omega – Using scp

- Turn on drag and drop for your virtual machine. to do this go to the settings in virtual box, and in the general menu go to the advanced sub-menu and change the drag’n’drop item to ’bidirectional’. this will allow you to drag and drop files between your regular OS and the virtual machine, you may need to restart the virtual machine for this to take effect.
- drag the executable from the virtual machine onto the desktop of your regular OS
- connect to your omegas wifi (password is 12345678 by default)

### 4.1 Mac or Linux Users

- Open terminal and cd into the directory where your exe is

$ scp <local file> root@192.168.3.1:/tmp

### 4.2 Windows Users

Note: to do this you must have PuTTy installed

- Open command prompt and cd into the directory where your exe is

$ pscp <local file> root@192.168.3.1: /tmp

### 4.3 Running The File

SSH to the omega, look at section 5 if unaware of how to do this

$ cd /tmp

$ ./<executable file>

## 5 SSH to the omega

What you will need

- connect to your omegas wifi (password is 12345678 by default)

### 5.1 Mac or Linux Users

- Open terminal

$ ssh root@192.168.3.1

– password is: onioneer by default

3

November 19, 2017 | ECE 150

### 5.2 Windows Users

Note: to do this you must have PuTTy installed

– Open PuTTy

– Under host name or ip address put 192.168.3.1 and then press Open

– username is: root

– password is: onioneer by default

The filesystem on the omega is within the folder ’/’ to get there run this command:

$ cd /

## 6 Troubleshooting USB-Stick

SSH to the omega
Make sure it is formatted to either exFat or Fat32
- If /tmp/mounts does not exit:

$ ls /dev

- At this point you should see something similar to sda1 in the directory if so follow the rest of this

$ mkdir /usb

$ mount /dev/sda1 /usb

- This will mount the usb drive to the folder /usb which we have just made

$ cd /usb

$ ls

- you should see the contents of your usb stick here

4

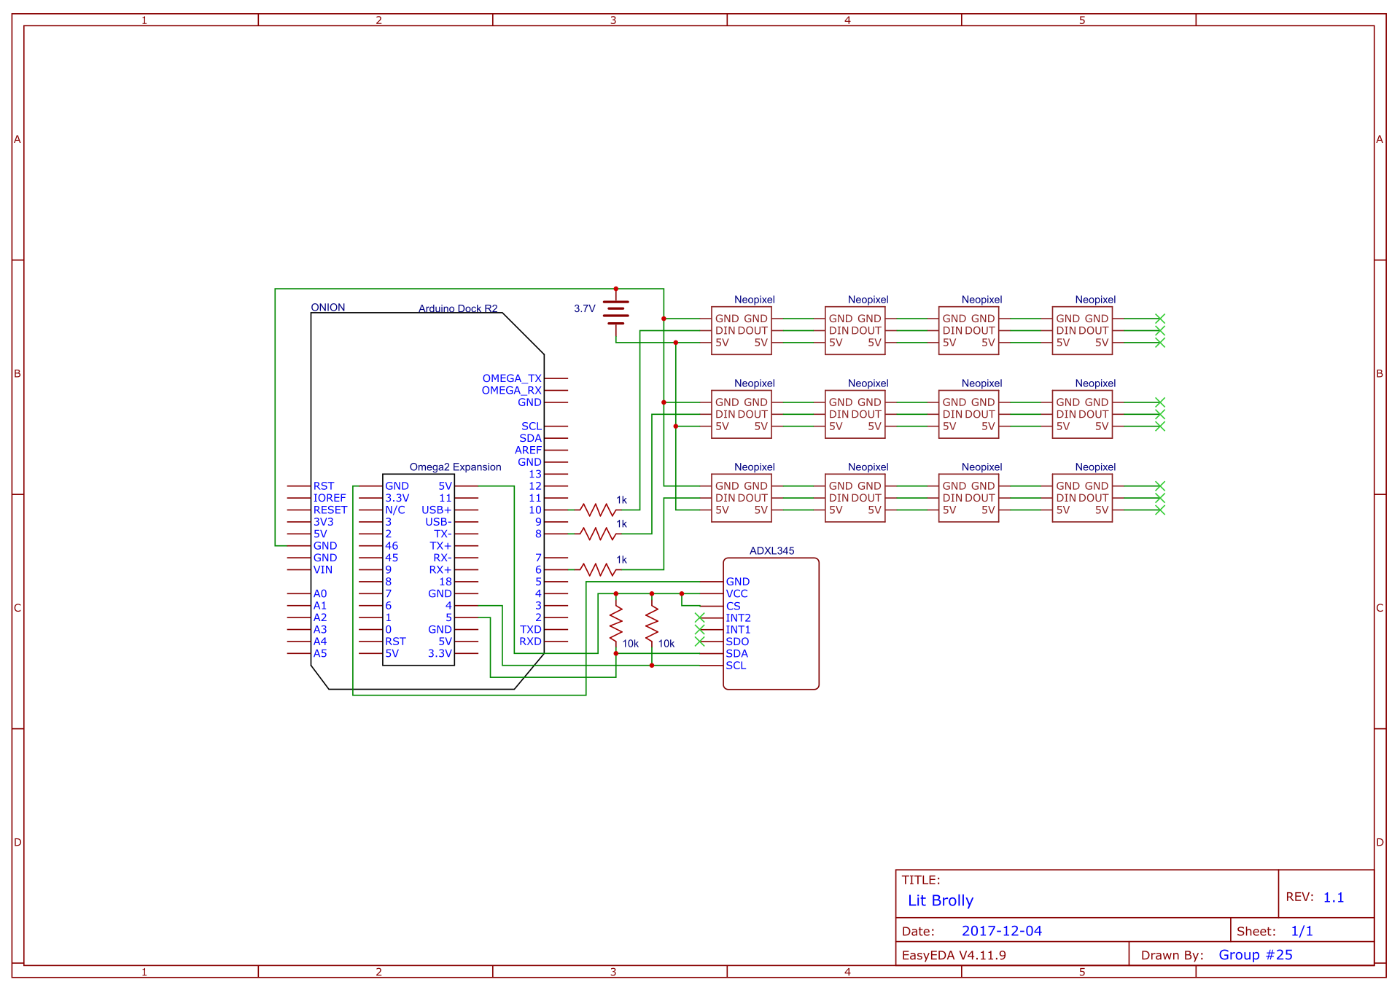
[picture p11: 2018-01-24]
Docs/Schematics/Main-Schematic.png

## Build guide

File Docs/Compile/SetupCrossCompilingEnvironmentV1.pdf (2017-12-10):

# Setting Up Cross Compiling For the Onion Omega 2

What you will need:

- Linux Environment – recommended to use Ubuntu
- Time – Lots of time

Note: If you are using the vdi file given out in the lab then step one and two are already done for you, and the ugpio library is already installed.

this guide will be following the onion setup guide on their

website but will be making changes where appropriate, and if any

errors occur, come to the WEEF TA office and they will fix

appropriately.

## 1 Setting up LEDE build System

This section will go over installing the LEDE build system and getting the correct libraries. Things in italics will be items to run in your command line terminal.

1. Run The following Commands to install the necessary packages and git repositories:

Note: This doc assumes this is done from the root directory.

$ sudo apt-get install -y git wget subversion build-essential libncurses5-dev zlib1g-dev gawk flex quilt git-core unzip libssl-dev python-dev python-pip libxml-parser-perl
$ git clone https://git.lede-project.org/source.git

This will take a fair bit of time depending on your internet speed.

2. Now download the various libraries you might need to compile with for your omega programs

i ) Library for GPIO pin reading

1

October 30, 2017 | ECE 150

a ) Make a folder that is readable by the menuconfig:

$ cd source

$ mkdir package/libs/libugpio

$ cd package/libs/libugpio

b ) Now get the ugpio package

$ wget https://dev.openwrt.org/export/35269/packages/libs/libugpio/Makefile

## 2 Installing the Base Build Chain

This section will go over the config of make and getting the libraries correctly installed.

$ cd source

$ make menuconfig

Note: if a GUI does not show up you need to make sure you are in the source directory, if that does not fix it go back to step one. The following section specifies what should be picked for each of the necessary settings

- Target Device: MediaTek Ralink MIPS
- Subtarget: MT76x8 based boards
- Target Profile Multiple Devices
- Target Devices Onion Omega2

Onion Omega 2+

To save your configuration go back to the main menu and use the left arrow key to get to save Do not change the name from .config, then exit the menuconfig.

- run

$ make

in the source folder this process will take a long time

Important: If a line similar to ”make build process failed” comes up, come to the WEEF TA office, and they will help you finish this process.

2

October 30, 2017 | ECE 150
- Upon completion your terminal should look something like this:

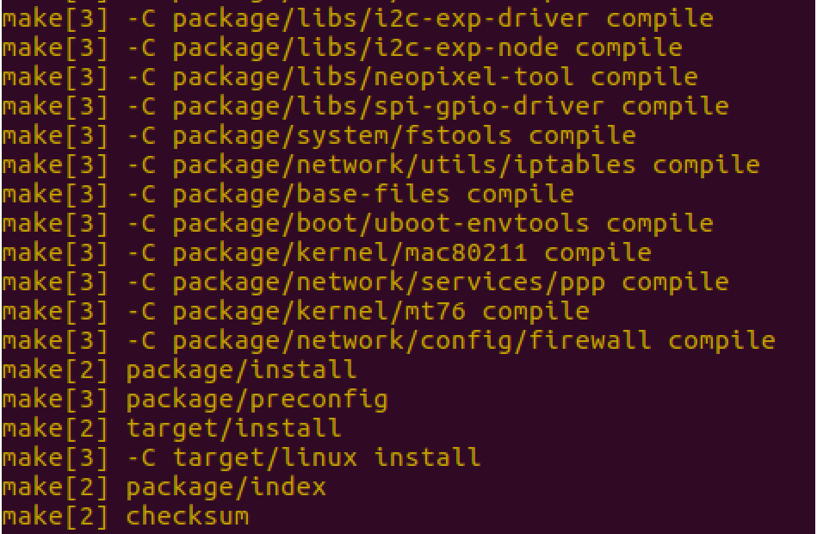
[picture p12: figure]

## 3 Installing Extra Libraries

This section will go over how to compile the libraries on the Omega2 onto your build chain

Note: For this project do not install any node or python libraries, this is a c++ course not a python or javascript course for more information on external library support for Omega 2 click here: Compiling External Libraries (https://onion.io/2bt-cross-compiling-c-programs-part-3/)

- Clone the following Github repository to get the needed files for installing the libraries while in the root directory
$ cd ~

$ git clone https://github.com/OnionIoT/OpenWRT-Packages.git

As of writing the following libraries will not compile and should not be used

- onion-st7735-driver
- libv8m-rb
- onion-ili9341-driver
1. Find the library you would like to install onto your buildchain, and move it to the following directory, then run the menuconfig again.
$ mv <path to package> ~/source/package/libs

$ cd ~/source

$ make menuconfig

3

October 30, 2017 | ECE 150
2. Now in the menu there should be a new heading called ”Onion”, select it go to libs, and select the library you just added. Save and exit the menuconfig.

$ make

3. That will compile your external libraries that you selected and you will now be ready to compile with them.

## 4 Compiling with xCompile.sh

Note: Before continuing make sure the xCompile.sh script, and the makefile from the example is inside of the folder that your .c file is.

- Change the following line in xCompile.sh:
TOOLCHAIN NAME=”toolchain-mipsel 24kc gcc-5.4.0 musl <– extra char-acters here remove them” TARGET NAME=”target-mipsel 24kc musl”
- Edit the makefile Target to be the name of your program without the file extension

$ sh xCompile.sh -buildroot /root/source/ -lib <put Libraries Here>

4

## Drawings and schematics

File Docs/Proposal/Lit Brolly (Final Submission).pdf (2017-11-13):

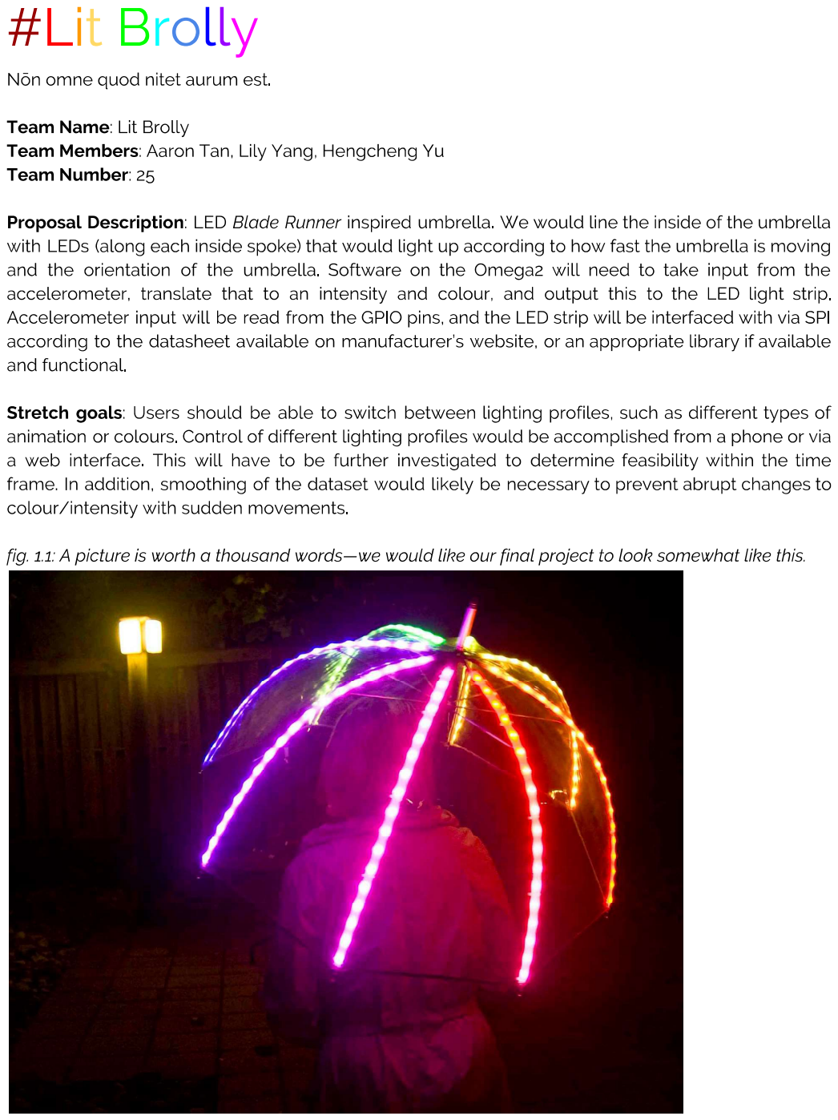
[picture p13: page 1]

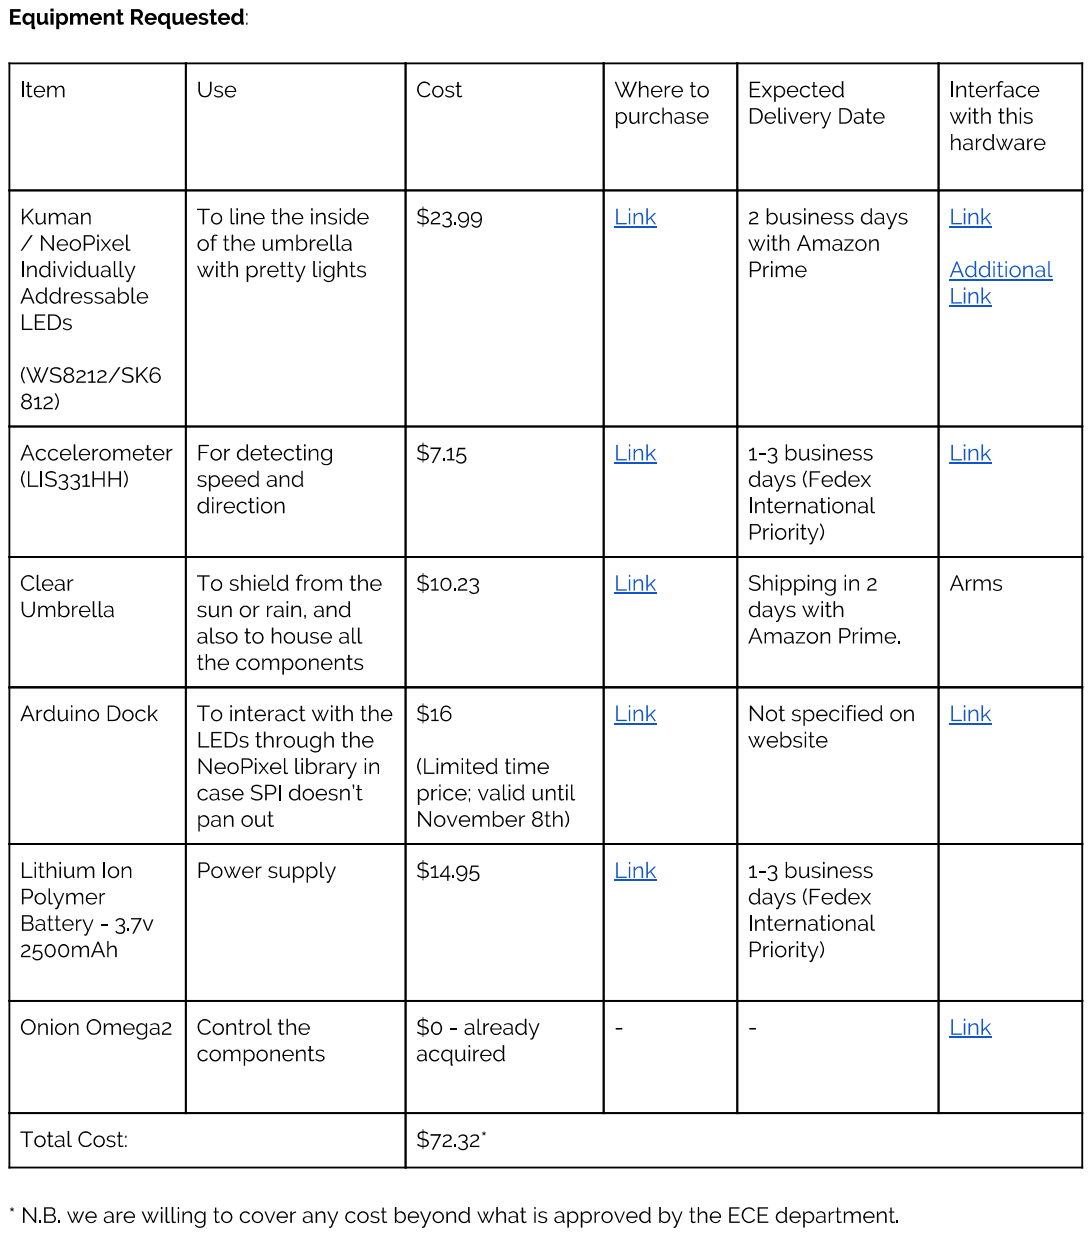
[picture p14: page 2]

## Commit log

2017-12-04 Milestone commit: Stuff works!
    Code pulls accelerometer readings every second over I2C, then alerts the
    Arduino dock over I2C to update colours on the Neopixels. X, Y, and Z
    accelerations map respectively to R, G, and B values.
2017-12-04 Updated Sketch
    Sketch should now be able to drive multiple strands, accepting input
    over I2C from pin 6 to 13 the ATMega headers.
2017-12-04 Removed unnecessary code from Arduino file
2018-01-19 Added some documentation
    [Main+Schematic.schdoc]
2018-01-24 Updated schematics
    Added more strands and cleaned up wires to make it seem cleaner
    [Main+Schematic.schdoc]
